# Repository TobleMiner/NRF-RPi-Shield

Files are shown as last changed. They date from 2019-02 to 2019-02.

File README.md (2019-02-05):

Raspberry Pi NRF Shield
=======================

Small and simple Shield for NRF24 wireless modules. Supports several SMD and non-SMD NRF24 footprints.

Backside provides footprints for installation of additional smoothing capacitors (please install at least one 100 nF capacitor, a lot of NRF modules become really unstable without one) and a 3.3 V regulator for use with high current draw NRF modules with builtin power amplifiers.

Goes well together with https://github.com/TobleMiner/kernelstuff/tree/master/modules/nrf24l01

PCB top

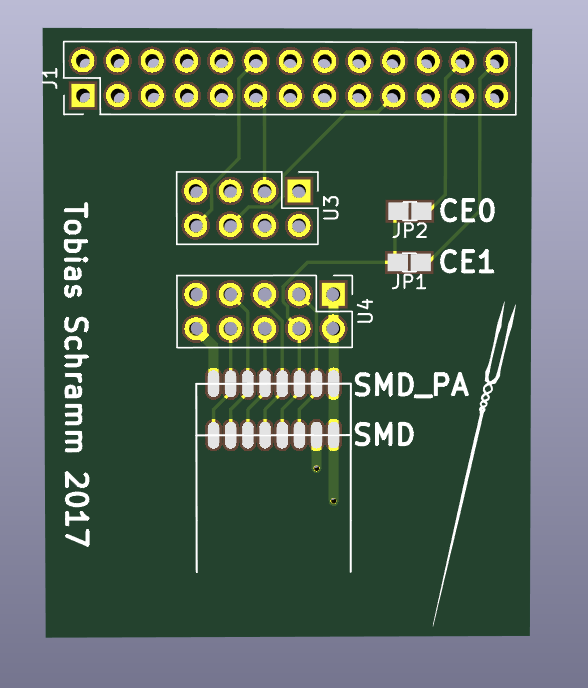
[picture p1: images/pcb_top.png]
PCB top


PCB bottom

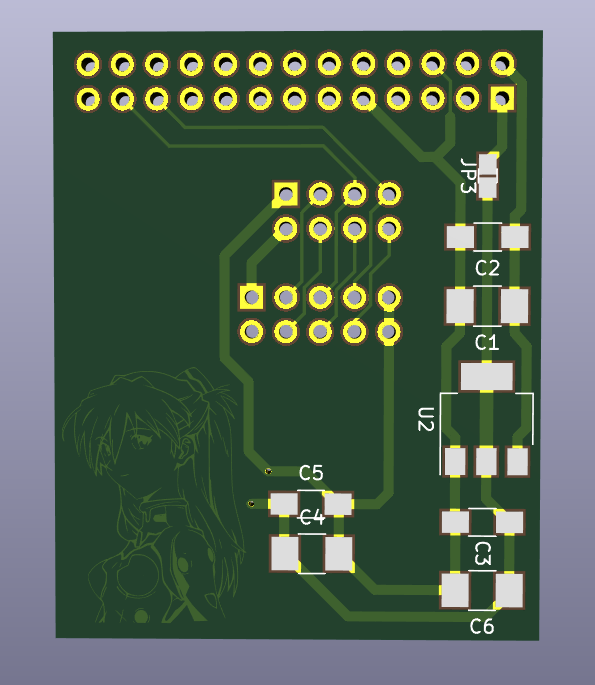
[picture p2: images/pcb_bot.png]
PCB bot


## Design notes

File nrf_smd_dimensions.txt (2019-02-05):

nrf_size:
width: 11,75 mm ~ 70 pixel
pin_spacing: 0.168 mm ~ 1 pixel
pin_width: 1.007 mm ~ 6 pixel
pin_raster: 1.17 mm
border: 0.671 mm ~ 4 pixel

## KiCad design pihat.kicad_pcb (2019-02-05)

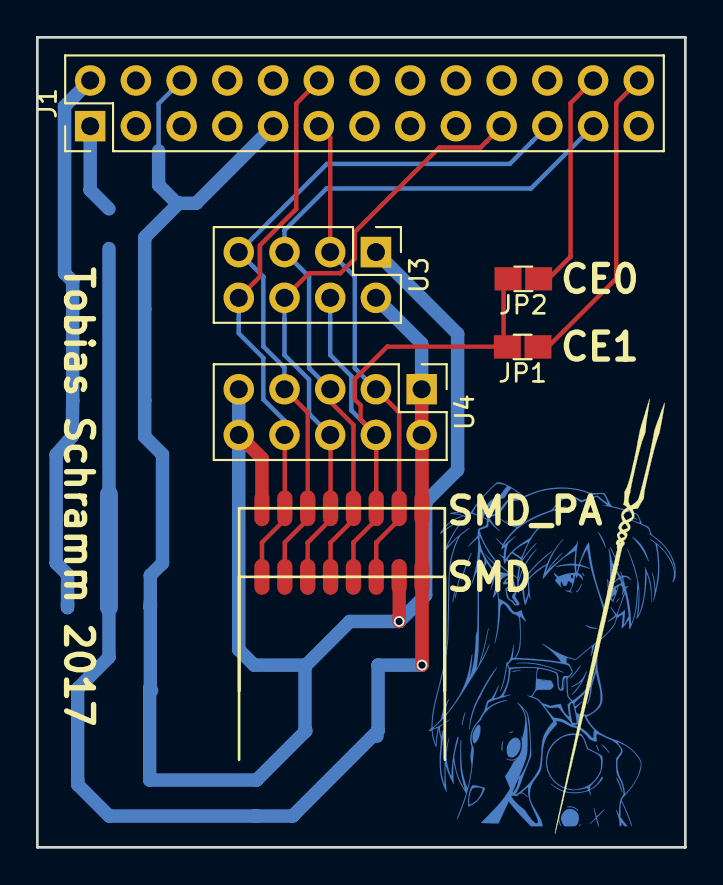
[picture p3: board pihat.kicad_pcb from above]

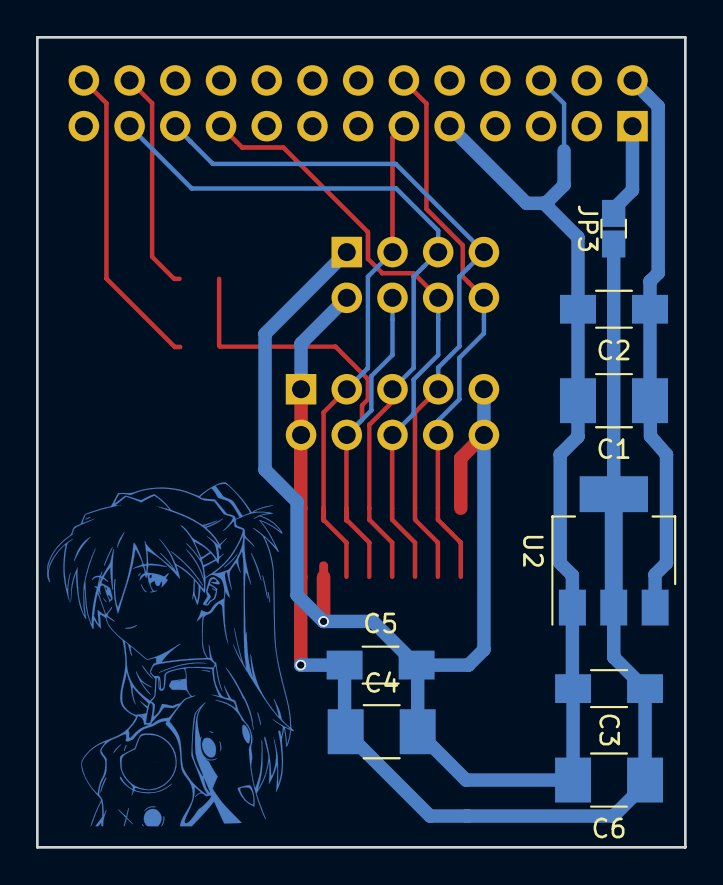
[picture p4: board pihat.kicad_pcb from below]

Board: 2 copper layers, 36.0 x 45.0 mm, 15 parts (8 on the bottom side), 12 nets.

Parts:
C1, C4, C6: 100µ; C_1210_HandSoldering
C2, C3, C5: 100n; C_1206_HandSoldering
J1: CONN_02X13; Pin_Header_Straight_2x13_Pitch2.54mm
JP1, JP2, JP3: Jumper_NO_Small; J_0603
U2: LM1117-3.3; SOT-223-3Lead_TabPin2
U3: nRF24L01+; Pin_Header_Straight_2x04_Pitch2.54mm
U4: nRF24L01+_10pin; Pin_Header_Straight_2x05_Pitch2.54mm
U5: nRF24L01P_SMD; nrf24l01_smd
U6: nRF24L01P_SMD_PA; nrf24l01_smd

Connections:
+3V3: C3.1, C4.1, C5.1, C6.1, JP3.1, U2.2, U3.2, U4.1, U4.2, U5.1, U6.1
+5V: C1.1, C2.1, J1.2, U2.3
/CE: J1.11, U3.3, U4.3, U5.3, U6.2
/CSN: JP1.2, JP2.2, U3.4, U4.4, U5.4, U6.3
/IRQ: J1.12, U3.8, U4.8, U5.8, U6.7
/MISO: J1.21, U3.7, U4.7, U5.7, U6.6
/MOSI: J1.19, U3.6, U4.6, U5.6, U6.5
/SCK: J1.23, U3.5, U4.5, U5.5, U6.4
GND: C1.2, C2.2, C3.2, C4.2, C5.2, C6.2, J1.6, J1.9, U2.1, U3.1, U4.9, U4.10, U5.2, U6.8
unnamed: J1.1, JP3.2
unnamed: J1.24, JP2.1
unnamed: J1.26, JP1.1

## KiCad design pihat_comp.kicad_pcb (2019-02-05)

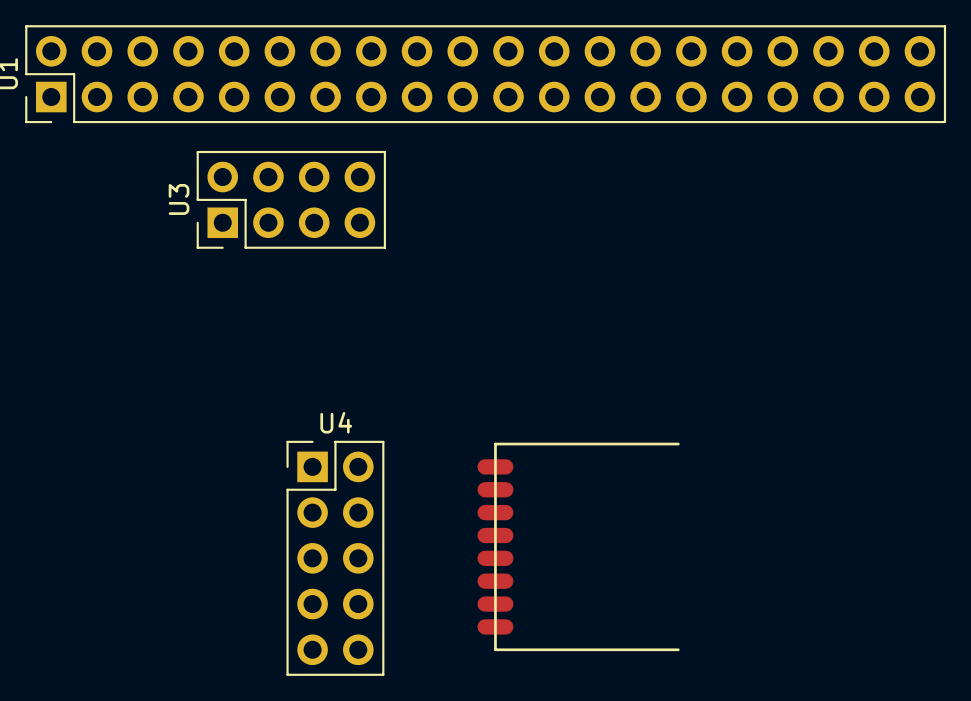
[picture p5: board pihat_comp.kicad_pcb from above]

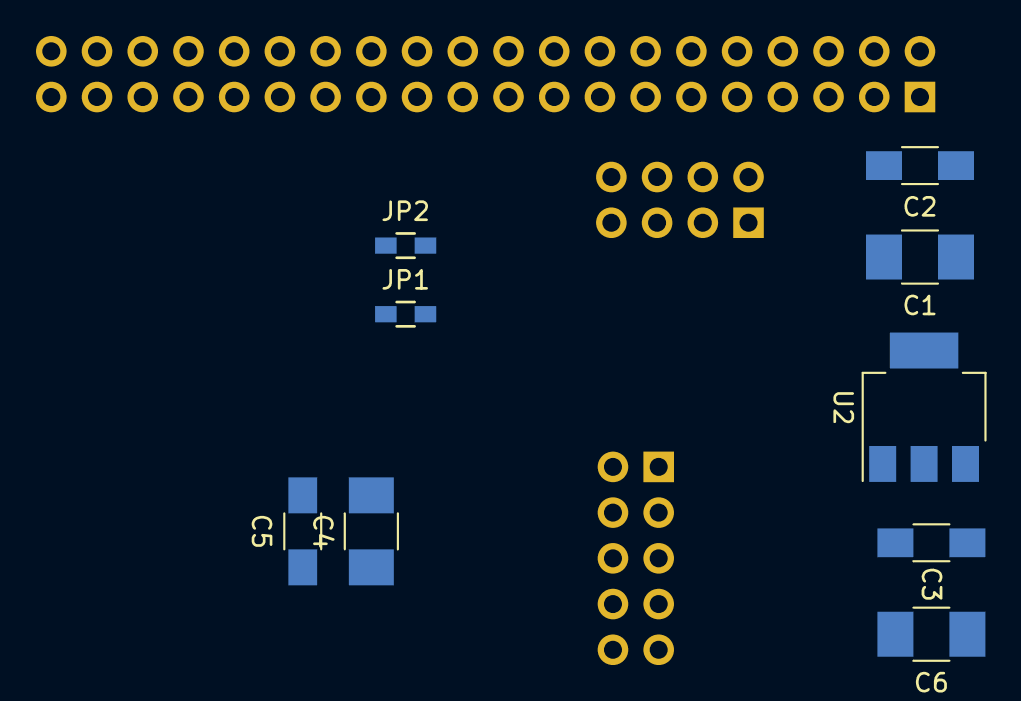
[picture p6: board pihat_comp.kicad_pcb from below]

Board: 2 copper layers, 13 parts (9 on the bottom side), 11 nets, no tracks yet.

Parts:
C1, C4, C6: 100µ; C_1210_HandSoldering
C2, C3, C5: 100n; C_1206_HandSoldering
JP1, JP2: Jumper_NO_Small; R_0603_HandSoldering
U1: Raspberry_Pi_2_3; Pin_Header_Straight_2x20_Pitch2.54mm
U2: LM1117-3.3; SOT-223-3Lead_TabPin2
U3: nRF24L01+; Pin_Header_Straight_2x04_Pitch2.54mm
U4: nRF24L01+_10pin; Pin_Header_Straight_2x05_Pitch2.54mm
U5: nRF24L01P_SMD; nrf24l01_smd

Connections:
+3V3: C3.1, C4.1, C5.1, C6.1, U1.1, U2.2, U3.2, U4.1, U5.1
+5V: C1.1, C2.1, U1.2, U2.3
/CE: U1.11, U3.3, U4.3, U5.3
/CSN: JP1.2, JP2.2, U3.4, U4.4, U5.4
/IRQ: U1.12, U3.8, U4.8, U5.8
/MISO: U1.21, U3.7, U4.7, U5.7
/MOSI: U1.19, U3.6, U4.6, U5.6
/SCK: U3.5, U4.5, U5.5
GND: C1.2, C2.2, C3.2, C4.2, C5.2, C6.2, U1.6, U2.1, U3.1, U4.9, U4.10, U5.2
unnamed: JP1.1, U1.26
unnamed: JP2.1, U1.24
